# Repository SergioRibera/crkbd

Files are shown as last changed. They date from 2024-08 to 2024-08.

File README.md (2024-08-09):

# Corne keyboard

The Corne keyboard is a split keyboard with 3x6 column staggered keys
and 3 thumb keys, based on [Helix](https://github.com/MakotoKurauchi/helix).
Crkbd stands for Corne Keyboard.

v4

## Latest versions
- corne-cherry: for Cherry MX compatible switches

  - v4 Hotswappable ([JP](docs/corne-cherry/v4/buildguide_jp.md)/[EN](docs/corne-cherry/v4/buildguide_en.md))
  - v4 Soldering (will be released)
- corne-chocolate: for Kailh choc v1 and v2 switches
  - v4 Hotswappable ([JP](docs/corne-chocolate/v4/buildguide_jp.md)/[EN](docs/corne-chocolate/v4/buildguide_en.md)):
  - v4 Soldering (will be released)

- [Corne v4 Cherry Wireless](./pcbs/cherry-wireless)

## Old versions

- corne-classic: for Cherry MX compatible switches 
  - v1 Soldering: ([JP](docs/corne-classic/buildguide_jp.md)/[EN](docs/corne-classic/buildguide_en.md))
- corne-cherry: for Cherry MX compatible switches
  - v2 Hotswappable: ([JP](docs/corne-cherry/v2/buildguide_jp.md)/[EN](docs/corne-cherry/v2/buildguide_en.md))
  - v2 Hotswappable tilting version: ([tilting, JP](docs/corne-cherry/v2/buildguide_tilting_tenting_plate_jp.md)/[tilting, EN](docs/corne-cherry/v2/buildguide_tilting_tenting_plate_en.md)):
  - v3 Hotswappable: ([JP](docs/corne-cherry/v3/buildguide_jp.md)/[EN](docs/corne-cherry/v3/buildguide_en.md))
- corne-chocolate: for Kailh choc v1 switches
  - v2 Hotswappable: ([JP](docs/corne-chocolate/v2/buildguide_jp.md)/[EN](docs/corne-chocolate/v2/buildguide_en.md)):
- corne-light: for easy build with a simple PCB
  - v1 Soldering: ([JP](docs/corne-light/v1/buildguide_jp.md)/[EN](docs/corne-light/v1/buildguide_en.md)):
  - v2 Soldering: ([JP](docs/corne-light/v2/buildguide_low_edition_jp.md)/[EN](docs/corne-light/v2/buildguide_low_edition_en.md)):

## Images

### Cherry
corne-cherry



### Chocolate
corne-chocolate



### Drawing
sketche

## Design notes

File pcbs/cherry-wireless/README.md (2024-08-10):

# Corne Keyboard Wireless Fork

This project is a customized fork of the popular Corne ergonomic keyboard.

> [!NOTE]
> As soon as I have my build I will upload pictures of the finished keyboard.

keyboard pcb

## Disclaimer

> [!IMPORTANT]
> **⚠️ IMPORTANT NOTICE: I am not an electronics expert ⚠️**
>
> This project has been carried out with the help of a professional contracted through Fiverr.
> If you have specific technical questions, I recommend consulting an expert.
>
> https://fiverr.com/pcbdesign_engr

## Features

- Custom layout based on the original Corne
- Hotswap Sockets
- Sk6812MiniE RGB LED per switch
- NRF52840-QIAA-R7 Microcontroller
- Differential pair routing from USB to MCU
- TypeC USB
- NiceView connector
- Removed extra keys added in v4

> [!NOTE]
> According to the engineer in charge, all components available at LCSC JLCPCB were used.

## Project Images

Back 2D
Renderred Back
3DD
3ddd

## Acknowledgements

This project would not have been possible without the help of a talented Fiverr professional. You can find their profile here: https://fiverr.com/pcbdesign_engr

I would also like to thank the original Corne Keyboard community for their incredible work and for inspiring this project.

## License

Use it as you wish, subject to the license of the original project.

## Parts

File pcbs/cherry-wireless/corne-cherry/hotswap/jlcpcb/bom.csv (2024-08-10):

Designator | Footprint | Quantity | Value | LCSC Part #
BT1, BT2, BT3, BT4, rBT1, rBT2, rBT3, rBT4 | Breakaway_Tabs | 8 | Breakaway Tabs
C1, C13, C14, C24, C25, C26, C35, C36, C41, C46, C51, C52 | 0402 | 12 | 4.7uF | C23733
C10, C2, C3, C32, C4, C42, C44, C45 | 0402 | 8 | 100nF | C307331
C11, C33 | 0402 | 2 | 100pF | C1546
C12, C34 | 0402 | 2 | 1nF | C1523
C15, C23, C37, C47, C49, C8 | 0402 | 6 | 1uF | C52923
C16, C38 | 0402 | 2 | 47nF | C312032
C17, C18, C29, C30, C39, C40, C6, C7 | 0402 | 8 | 15pF | C1548
C19, C43 | 0402 | 2 | 100nF | C1525
C20, C50 | 0402 | 2 | 4.7uF
C21, C48 | 0603 | 2 | 10uF | C19702
C22, C27 | 0402 | 2 | 1.5pF | C1552
C28, C31, C5, C9 | 0402 | 4 | 1pF | C1550
D1, rD1 | D_SOD-523 | 2 | 1N4148WT
D2, D4 | 0402 | 2 | BLUE | C364550
D3, D7 | 0402 | 2 | ORANGE | C364554
D5, D6 | D_SOD-323F | 2 | PMEG4010CEJ | C50704
J1, J7 | USB-C_C168688 | 2 | USB_C_Receptacle_USB2.0 | C168688
J11, J3 | PinHeader_1x05_P2.54mm_Vertical | 2 | Screw_Terminal_01x05
J12, J13 | CONN-SMD_SM02B-PASS-TLFSN | 2 | Conn_01x02_Shielded
J2, rJ2 | PJ-398A-5A_PJ-399B-6A | 2 | TRS
J6, J8 | PinHeader_1x03_P2.54mm_Vertical | 2 | Conn_01x03
L1, L5 | 0402 | 2 | 3.9nH | C14033
L2, L6 | 0402 | 2 | 15nH | C27143
L3, L4, L7, L8 | 0603 | 4 | 10uH | C1035
LED1, LED10, LED11, LED12, LED13, LED14, LED15, LED16, LED17, LED18, LED19, LED2, LED20, LED21, LED3, LED4, LED5, LED6, LED7, LED8, LED9, rLED1, rLED10, rLED11, rLED12, rLED13, rLED14, rLED15, rLED16, rLED17, rLED18, rLED19, rLED2, rLED20, rLED21, rLED3, rLED4, rLED5, rLED6, rLED7, rLED8, rLED9 | YS-SK6812MINI-E_crone | 42 | YS-SK6812MINI-E | C5149201
NT1, NT2 | net-tie-2-tiny | 2 | NetTie_2
R1, R13 | 0402 | 2 | 3.9k | C131467
R10, R16, R17, R9 | 0402 | 4 | 5.1k | C105872
R11, R3 | 0402 | 2 | 0R | C17168
R12, R15, R18, R6, R7, R8 | 0402 | 6 | 10k | C25744
R14, R2 | 0402 | 2 | 2M | C138014
R4, R5 | 0402 | 2 | 1.5k | C114759
SW1, rSW1 | keyswitch_cherrymx_hotswap_1.5u | 2 | SW_Push | C2803348
SW10, SW11, SW12, SW13, SW14, SW15, SW16, SW17, SW18, SW19, SW2, SW20, SW21, SW3, SW4, SW5, SW6, SW7, SW8, SW9, rSW10, rSW11, rSW12, rSW13, rSW14, rSW15, rSW16, rSW17, rSW18, rSW19, rSW2, rSW20, rSW21, rSW3, rSW4, rSW5, rSW6, rSW7, rSW8, rSW9 | keyswitch_cherrymx_hotswap_1u | 40 | SW_Push | C2803348
SW22, SW23 | SW-SMD-TS-1088-AR02016 | 2 | SW_SPST
U1, U4 | AQFN-73-1EP_7x7mm_P0.5mm_NRF52840-custom | 2 | NRF52840-QIAA-R7 | C190794
U10, U6 | TDFN-8-1EP_2x2mm_P0.5mm_EP0.8x1.2mm | 2 | MAX17048 | C2682616
U2, U7 | VQFN-16-1EP_3x3mm_P0.5mm_EP1.6x1.6mm | 2 | BQ24075RGT | C2865459
U3, U8 | TSOT-23-5 | 2 | XC6220B331MR | C86534
U5, U9 | UDFN-6_1.2x1.0mm_P0.4mm | 2 | ESDR0502NMUTAG | C94372
Y1, Y3 | Crystal_SMD_2016-4Pin_2.0x1.6mm | 2 | 32MHz | C255896
Y2, Y4 | Crystal_SMD_2012-2Pin_2.0x1.2mm | 2 | 32.768 kHz | C97607
rJP1 | SolderJumper-2_P1.3mm_Open_RoundedPad1.0x1.5mm | 1 | SolderJumper_2_Bridged

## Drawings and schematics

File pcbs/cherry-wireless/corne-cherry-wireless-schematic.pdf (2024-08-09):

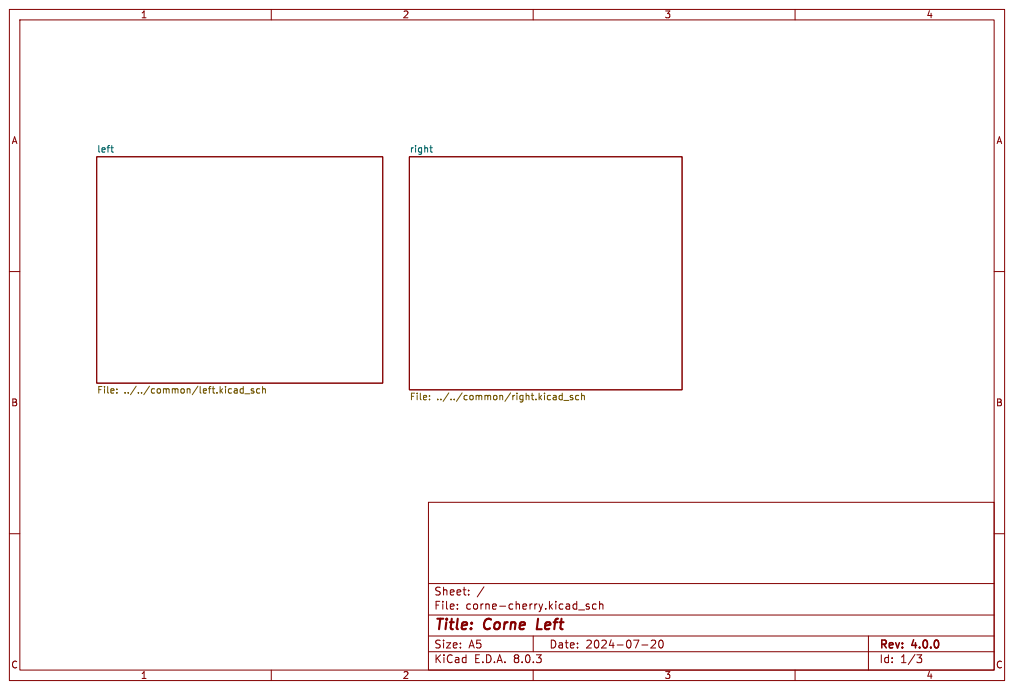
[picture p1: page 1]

left File: ../../common/left.kicad_sch

right File: ../../common/right.kicad_sch

Id: 1/3 Title: Corne Left File: corne-cherry.kicad_sch Sheet: /

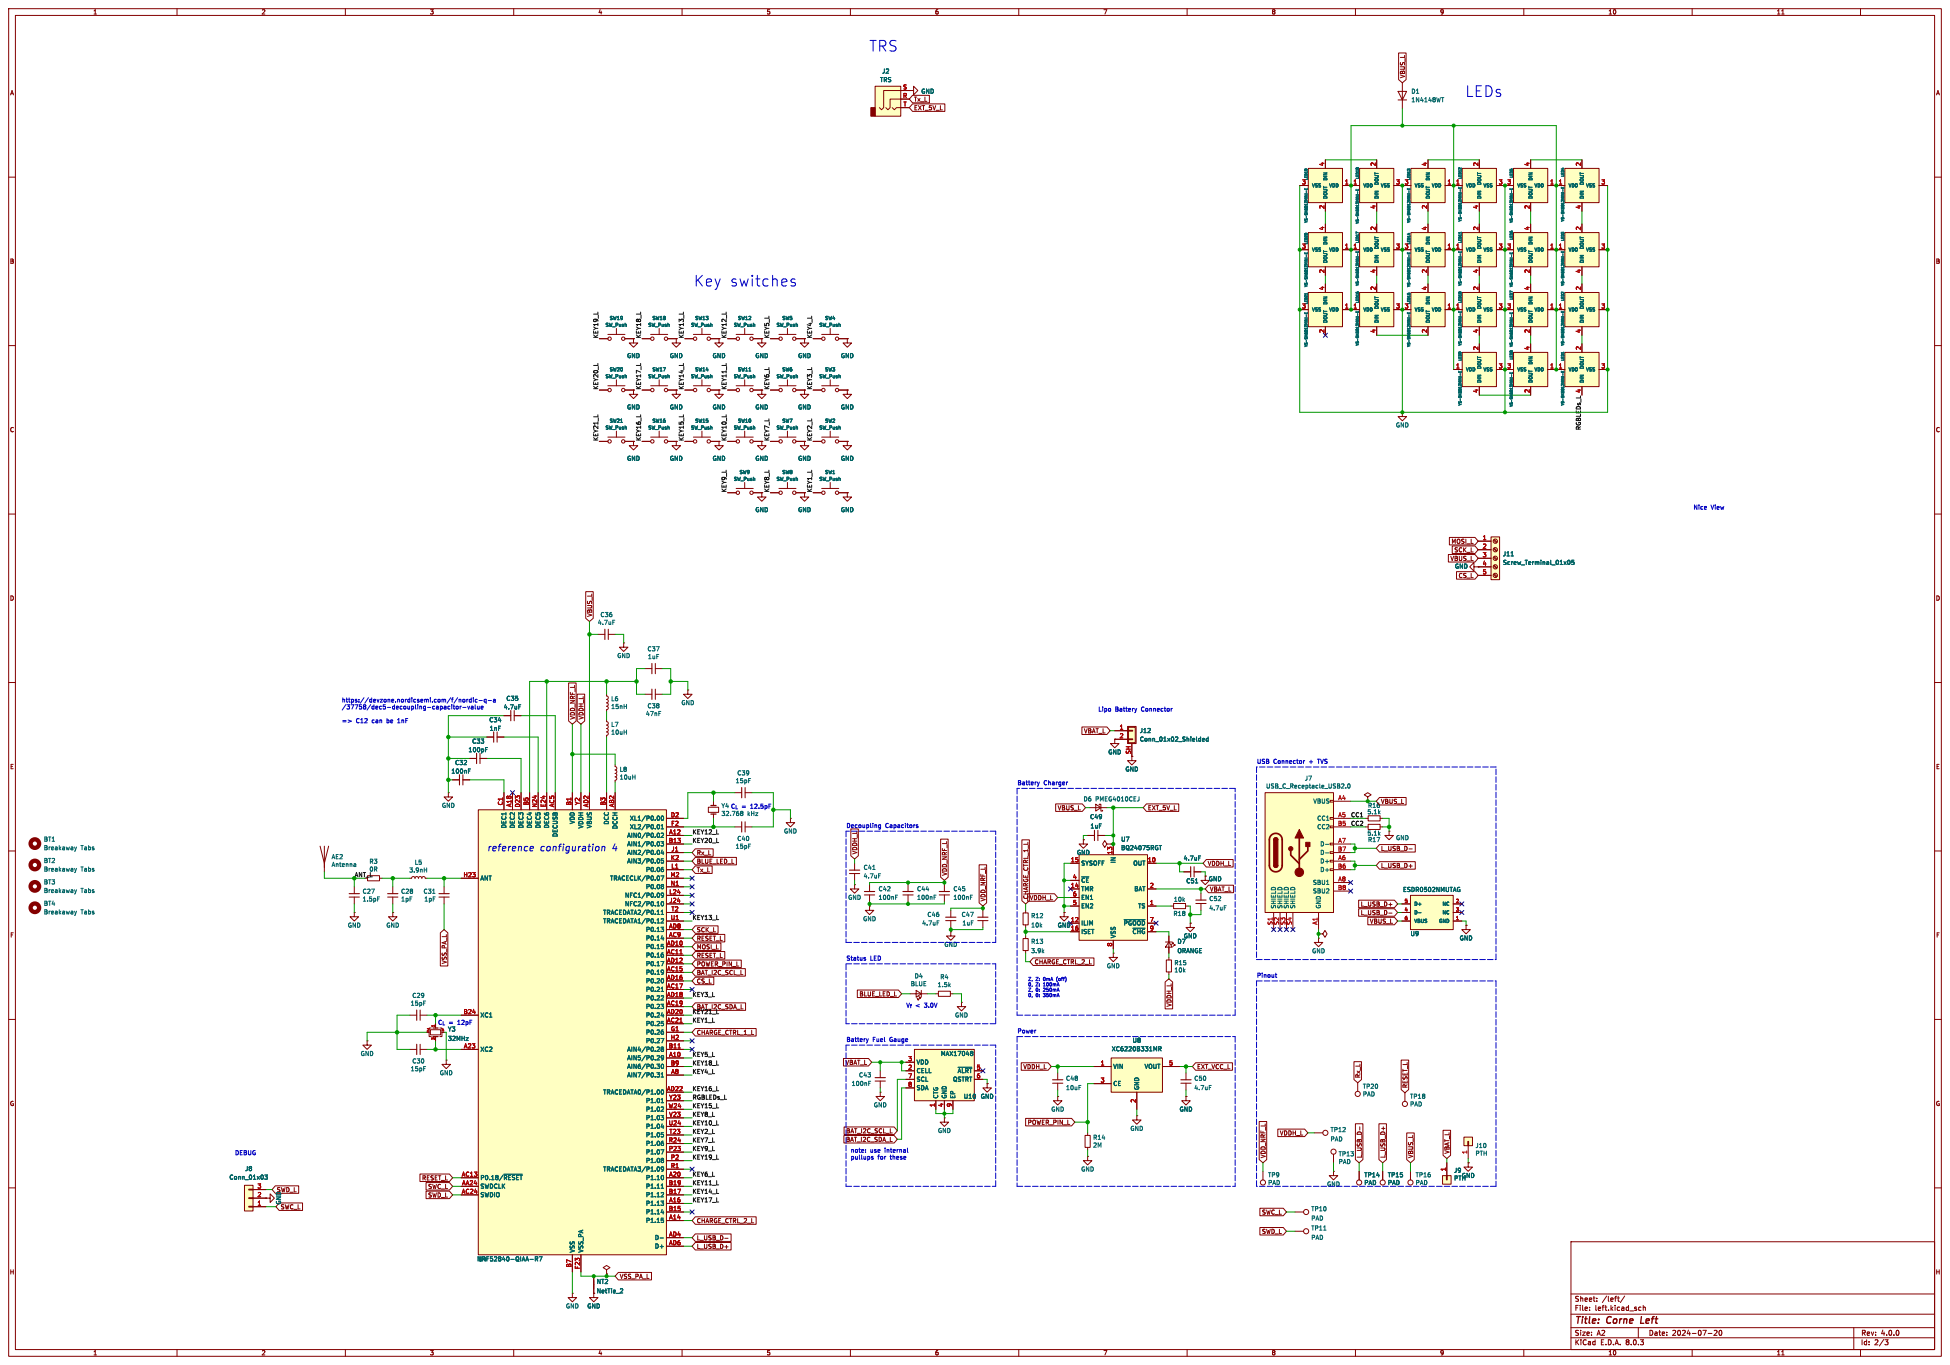
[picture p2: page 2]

VSS 3 DIN 4 LED12 YS-SK6812MINI-E VDD 1 DOUT 2

VSS 3 DIN 4 LED3 YS-SK6812MINI-E VDD 1 DOUT 2

https://devzone.nordicsemi.com/f/nordic-q-a

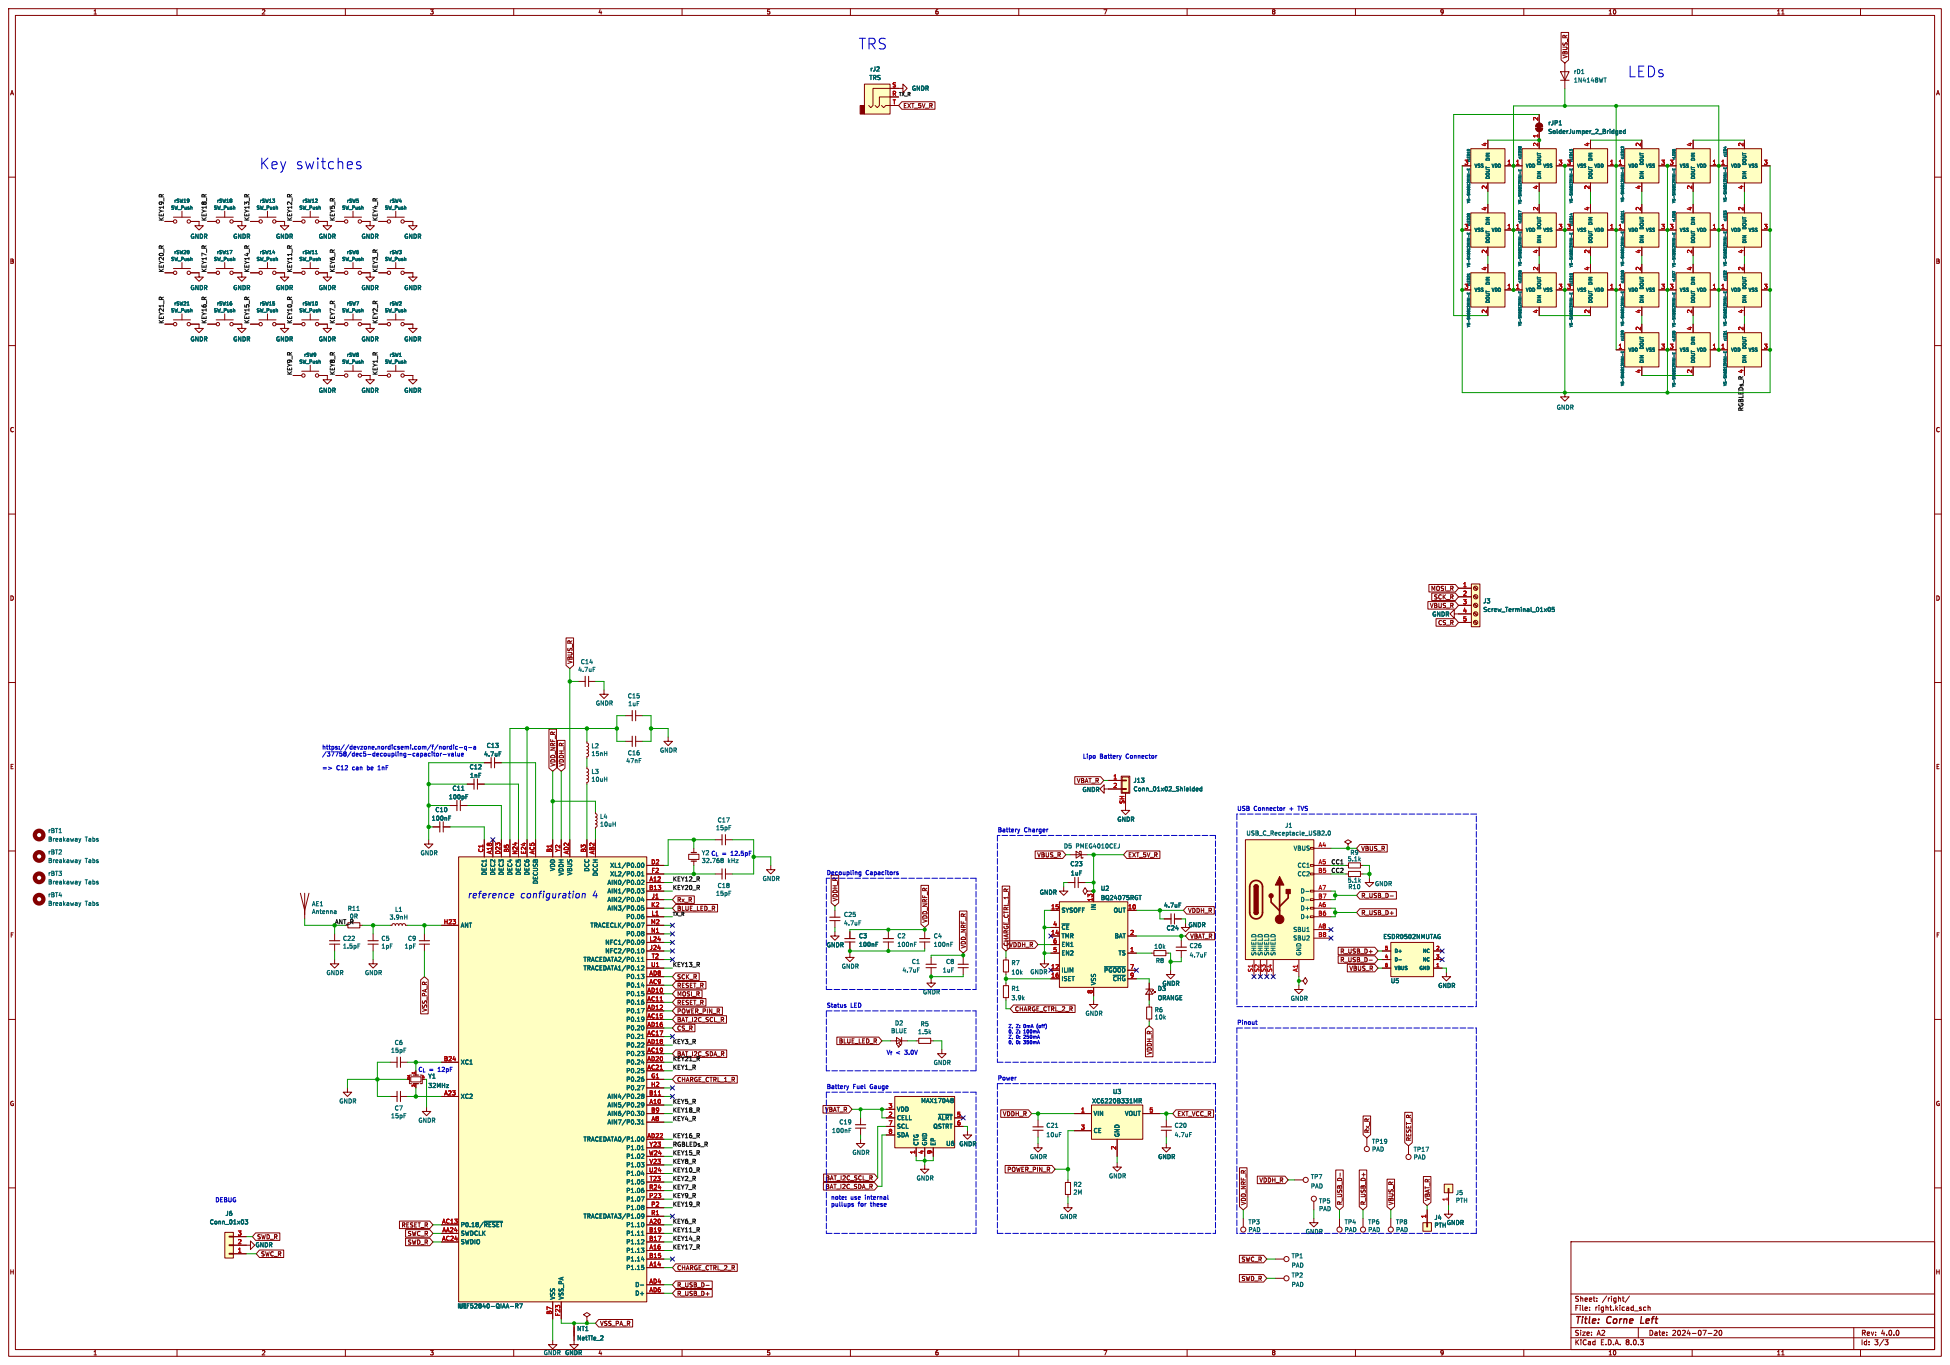
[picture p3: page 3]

https://devzone.nordicsemi.com/f/nordic-q-a

2 CE 3 VOUT 5 GNDR GNDR

4 ~{ALRT}5 QSTRT 6 SCL 7 SDA 8 EP

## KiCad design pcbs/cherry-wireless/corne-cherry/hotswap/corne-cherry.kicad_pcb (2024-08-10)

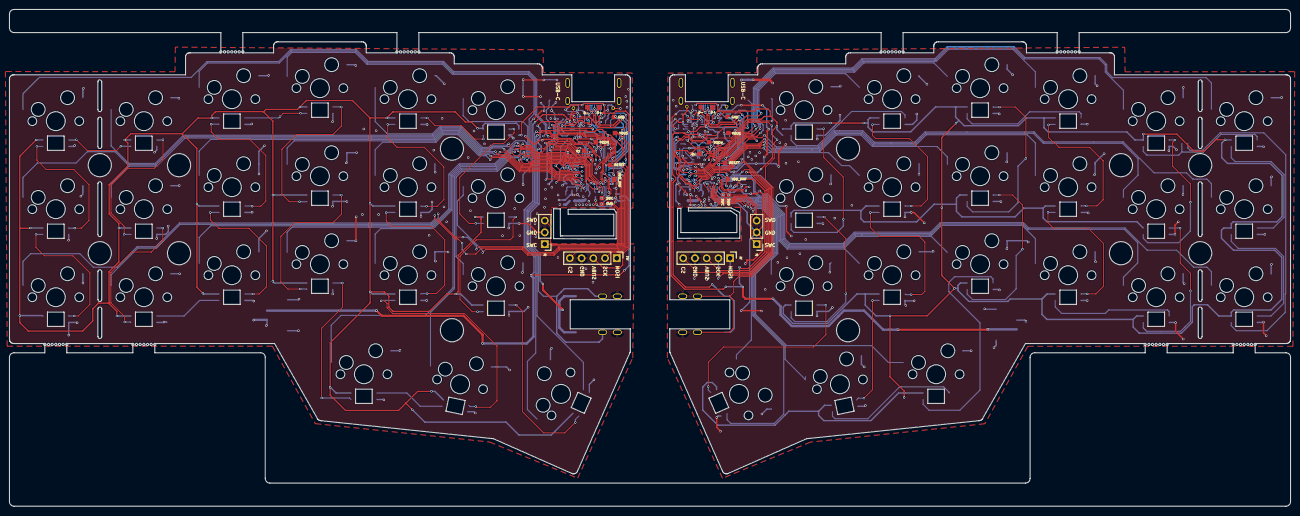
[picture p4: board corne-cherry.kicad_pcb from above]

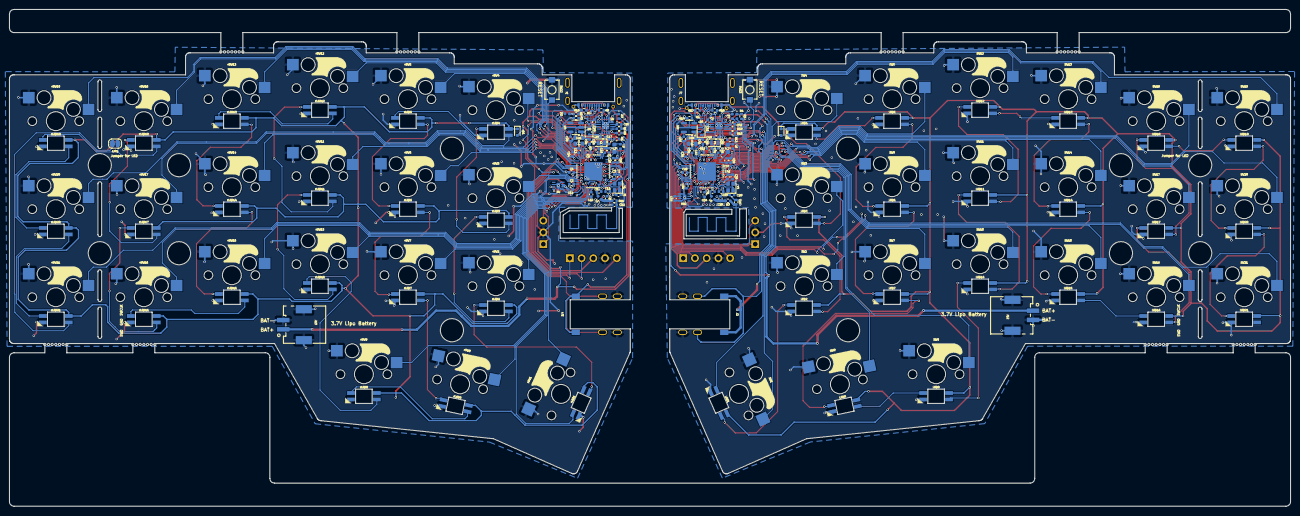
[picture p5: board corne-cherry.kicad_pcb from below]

Board: 2 copper layers, 277.2 x 107.5 mm, 233 parts (201 on the bottom side), 179 nets.

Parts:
AE1, AE2: Antenna; 2.4GHz-meander-antenna-v2
BT1, BT2, BT3, BT4: Breakaway Tabs; Breakaway_Tabs
C1, C13, C14, C20, C24, C25, C26, C35, C36, C41, C46, C50, C51, C52: 4.7uF; C_0402_1005Metric
C2, C3, C4, C10, C19, C32, C42, C43, C44, C45: 100nF; C_0402_1005Metric
C5, C9, C28, C31: 1pF; C_0402_1005Metric
C6, C7, C17, C18, C29, C30, C39, C40: 15pF; C_0402_1005Metric
C8, C15, C23, C37, C47, C49: 1uF; C_0402_1005Metric
C11, C33: 100pF; C_0402_1005Metric
C12, C34: 1nF; C_0402_1005Metric
C16, C38: 47nF; C_0402_1005Metric
C21, C48: 10uF; C_0603_1608Metric
C22, C27: 1.5pF; C_0402_1005Metric
D1: 1N4148WT; D_SOD-523
D2, D4: BLUE; LED_0402_1005Metric
D3, D7: ORANGE; LED_0402_1005Metric
D5, D6: PMEG4010CEJ; D_SOD-323F
J1, J7: USB_C_Receptacle_USB2.0; USB-C_C168688
J2: TRS; PJ-398A-5A_PJ-399B-6A
J3, J11: Screw_Terminal_01x05; PinHeader_1x05_P2.54mm_Vertical
J4, J5, J9, J10: PTH; PTH-0.8_0.45mm
J6, J8: Conn_01x03; PinHeader_1x03_P2.54mm_Vertical
J12, J13: Conn_01x02_Shielded; CONN-SMD_SM02B-PASS-TLFSN
L1, L5: 3.9nH; L_0402_1005Metric
L2, L6: 15nH; L_0402_1005Metric
L3, L4, L7, L8: 10uH; L_0603_1608Metric
LED1, LED2, LED3, LED4, LED5, LED6, LED7, LED8, LED9, LED10, LED11, LED12, LED13, LED14, LED15, LED16, LED17, LED18, LED19, LED20, LED21: YS-SK6812MINI-E; YS-SK6812MINI-E_crone
NT1, NT2: NetTie_2; net-tie-2-tiny
R1, R13: 3.9k; R_0402_1005Metric
R2, R14: 2M; R_0402_1005Metric
R3, R11: 0R; R_0402_1005Metric
R4, R5: 1.5k; R_0402_1005Metric
R6, R7, R8, R12, R15, R18: 10k; R_0402_1005Metric
R9, R10, R16, R17: 5.1k; R_0402_1005Metric
SW1: SW_Push; keyswitch_cherrymx_hotswap_1.5u
SW2, SW3, SW4, SW5, SW6, SW7, SW8, SW9, SW10, SW11, SW12, SW13, SW14, SW15, SW16, SW17, SW18, SW19, SW20, SW21: SW_Push; keyswitch_cherrymx_hotswap_1u
SW22, SW23: SW_SPST; SW-SMD-TS-1088-AR02016
TP1, TP2, TP3, TP4, TP5, TP6, TP7, TP8, TP9, TP10, TP11, TP12, TP13, TP14, TP15, TP16, TP17, TP18, TP19, TP20: PAD; TestPoint_Pad_1.0x1.0mm-nosilk
U1, U4: NRF52840-QIAA-R7; AQFN-73-1EP_7x7mm_P0.5mm_NRF52840-custom
U2, U7: BQ24075RGT; VQFN-16-1EP_3x3mm_P0.5mm_EP1.6x1.6mm
U3, U8: XC6220B331MR; TSOT-23-5
U5, U9: ESDR0502NMUTAG; UDFN-6_1.2x1.0mm_P0.4mm
U6, U10: MAX17048; TDFN-8-1EP_2x2mm_P0.5mm_EP0.8x1.2mm
Y1, Y3: 32MHz; Crystal_SMD_2016-4Pin_2.0x1.6mm
Y2, Y4: 32.768 kHz; Crystal_SMD_2012-2Pin_2.0x1.2mm
rBT1, rBT2, rBT3, rBT4: Breakaway Tabs; Breakaway_Tabs
rD1: 1N4148WT; D_SOD-523
rJ2: TRS; PJ-398A-5A_PJ-399B-6A
rJP1: SolderJumper_2_Bridged; SolderJumper-2_P1.3mm_Open_RoundedPad1.0x1.5mm
rLED1, rLED2, rLED3, rLED4, rLED5, rLED6, rLED7, rLED8, rLED9, rLED10, rLED11, rLED12, rLED13, rLED14, rLED15, rLED16, rLED17, rLED18, rLED19, rLED20, rLED21: YS-SK6812MINI-E; YS-SK6812MINI-E_crone
rSW1: SW_Push; keyswitch_cherrymx_hotswap_1.5u
rSW2, rSW3, rSW4, rSW5, rSW6, rSW7, rSW8, rSW9, rSW10, rSW11, rSW12, rSW13, rSW14, rSW15, rSW16, rSW17, rSW18, rSW19, rSW20, rSW21: SW_Push; keyswitch_cherrymx_hotswap_1u

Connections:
/left/ANT_L: AE2.1 (A), C27.2, R3.2
/left/CC1: J7.A5 (CC1), R16.1
/left/CC2: J7.B5 (CC2), R17.1
/left/KEY1_L: SW1.1, U4.AC21 (P0.25)
/left/KEY2_L: SW2.1, U4.T23 (P1.05)
/left/KEY3_L: SW3.1, U4.AD18 (P0.22)
/left/KEY4_L: SW4.1, U4.A8 (AIN7/P0.31)
/left/KEY5_L: SW5.1, U4.A10 (AIN5/P0.29)
/left/KEY6_L: SW6.1, U4.A20 (P1.10)
/left/KEY7_L: SW7.1, U4.R24 (P1.06)
/left/KEY8_L: SW8.1, U4.V23 (P1.03)
/left/KEY9_L: SW9.1, U4.P23 (P1.07)
/left/KEY10_L: SW10.1, U4.U24 (P1.04)
/left/KEY11_L: SW11.1, U4.B19 (P1.11)
/left/KEY12_L: SW12.1, U4.A12 (AIN0/P0.02)
/left/KEY13_L: SW13.1, U4.U1 (TRACEDATA1/P0.12)
/left/KEY14_L: SW14.1, U4.B17 (P1.12)
/left/KEY15_L: SW15.1, U4.W24 (P1.02)
/left/KEY16_L: SW16.1, U4.AD22 (TRACEDATA0/P1.00)
/left/KEY17_L: SW17.1, U4.A16 (P1.13)
/left/KEY18_L: SW18.1, U4.B9 (AIN6/P0.30)
/left/KEY19_L: SW19.1, U4.P2 (P1.08)
/left/KEY20_L: SW20.1, U4.B13 (AIN1/P0.03)
/left/KEY21_L: SW21.1, U4.AD20 (P0.24)
/left/RGBLEDs_L: LED1.4 (DIN), U4.Y23 (P1.01)
/right/ANT_R: AE1.1 (A), C22.2, R11.2
/right/CC1: J1.A5 (CC1), R9.1
/right/CC2: J1.B5 (CC2), R10.1
/right/KEY1_R: U1.AC21 (P0.25), rSW1.1
/right/KEY2_R: U1.T23 (P1.05), rSW2.1
/right/KEY3_R: U1.AD18 (P0.22), rSW3.1
/right/KEY4_R: U1.A8 (AIN7/P0.31), rSW4.1
/right/KEY5_R: U1.A10 (AIN5/P0.29), rSW5.1
/right/KEY6_R: U1.A20 (P1.10), rSW6.1
/right/KEY7_R: U1.R24 (P1.06), rSW7.1
/right/KEY8_R: U1.V23 (P1.03), rSW8.1
/right/KEY9_R: U1.P23 (P1.07), rSW9.1
/right/KEY10_R: U1.U24 (P1.04), rSW10.1
/right/KEY11_R: U1.B19 (P1.11), rSW11.1
/right/KEY12_R: U1.A12 (AIN0/P0.02), rSW12.1
/right/KEY13_R: U1.U1 (TRACEDATA1/P0.12), rSW13.1
/right/KEY14_R: U1.B17 (P1.12), rSW14.1
/right/KEY15_R: U1.W24 (P1.02), rSW15.1
/right/KEY16_R: U1.AD22 (TRACEDATA0/P1.00), rSW16.1
/right/KEY17_R: U1.A16 (P1.13), rSW17.1
/right/KEY18_R: U1.B9 (AIN6/P0.30), rSW18.1
/right/KEY19_R: U1.P2 (P1.08), rSW19.1
/right/KEY20_R: U1.B13 (AIN1/P0.03), rSW20.1
/right/KEY21_R: U1.AD20 (P0.24), rSW21.1
/right/RGBLEDs_R: U1.Y23 (P1.01), rLED1.4 (DIN)
/right/TX_R: U1.L1 (P0.06), rJ2.R
BAT_I2C_SCL_L: U4.AC15 (P0.19), U10.7 (SCL)
BAT_I2C_SCL_R: U1.AC15 (P0.19), U6.7 (SCL)
BAT_I2C_SDA_L: U4.AC19 (P0.23), U10.8 (SDA)
BAT_I2C_SDA_R: U1.AC19 (P0.23), U6.8 (SDA)
BLUE_LED_L: D4.2 (A), U4.K2 (AIN3/P0.05)
BLUE_LED_R: D2.2 (A), U1.K2 (AIN3/P0.05)
CHARGE_CTRL_1_L: R12.1, U4.G1 (P0.26)
CHARGE_CTRL_1_R: R7.1, U1.G1 (P0.26)
CHARGE_CTRL_2_L: R13.2, U4.A14 (P1.15)
CHARGE_CTRL_2_R: R1.2, U1.A14 (P1.15)
CS_L: J11.5, U4.AD16 (P0.20)
CS_R: J3.5, U1.AD16 (P0.20)
EXT_5V_L: C49.1, D6.1 (K), J2.T, U7.13 (IN)
EXT_5V_R: C23.1, D5.1 (K), U2.13 (IN), rJ2.T
EXT_VCC_L: C50.2, U8.5 (VOUT)
EXT_VCC_R: C20.2, U3.5 (VOUT)
GND: C27.1, C28.1, C29.2, C30.2, C32.2, C33.2, C34.2, C35.2, C36.1, C37.1, C38.1, C39.1, C40.1, C41.1, C42.1, C43.1, C44.1, C45.1, C46.1, C47.1, C48.1, C49.2, C50.1, C51.1, C52.1, J2.S, J7.A1 (GND), J8.2, J10.1, J11.4, J12.2, J12.SH (Shield), LED1.3 (VSS), LED2.3 (VSS), LED3.3 (VSS), LED4.3 (VSS), LED5.3 (VSS), LED6.3 (VSS), LED7.3 (VSS), LED8.3 (VSS), LED9.3 (VSS), LED10.3 (VSS), LED11.3 (VSS), LED12.3 (VSS), LED13.3 (VSS), LED14.3 (VSS), LED15.3 (VSS), LED16.3 (VSS), LED17.3 (VSS), LED18.3 (VSS), LED19.3 (VSS), LED20.3 (VSS), LED21.3 (VSS), NT2.2, R4.1, R14.2, R16.2, R17.2, R18.2, SW1.2, SW2.2, SW3.2, SW4.2, SW5.2, SW6.2, SW7.2, SW8.2, SW9.2, SW10.2, SW11.2, SW12.2, SW13.2, SW14.2, SW15.2, SW16.2, SW17.2, SW18.2, SW19.2, SW20.2, SW21.2, SW23.2 (B), TP13.1, U4.B7 (VSS), U4.EP (VSS), U7.4 (~CE), U7.5 (EN2), U7.8 (VSS), U7.15 (SYSOFF), U7.17 (VSS), U8.2 (GND), U9.1 (GND), U10.1 (CTG), U10.4 (GND), U10.6 (QSTRT), U10.9 (EP), Y3.2, Y3.4
GNDR: C1.1, C2.1, C3.1, C4.1, C5.1, C6.2, C7.2, C8.1, C10.2, C11.2, C12.2, C13.2, C14.1, C15.1, C16.1, C17.1, C18.1, C19.1, C20.1, C21.1, C22.1, C23.2, C24.1, C25.1, C26.1, J1.A1 (GND), J3.4, J5.1, J6.2, J13.2, J13.SH (Shield), NT1.2, R2.2, R5.1, R8.2, R9.2, R10.2, SW22.2 (B), TP5.1, U1.B7 (VSS), U1.EP (VSS), U2.4 (~CE), U2.5 (EN2), U2.8 (VSS), U2.15 (SYSOFF), U2.17 (VSS), U3.2 (GND), U5.1 (GND), U6.1 (CTG), U6.4 (GND), U6.6 (QSTRT), U6.9 (EP), Y1.2, Y1.4, rJ2.S, rLED1.3 (VSS), rLED2.3 (VSS), rLED3.3 (VSS), rLED4.3 (VSS), rLED5.3 (VSS), rLED6.3 (VSS), rLED7.3 (VSS), rLED8.3 (VSS), rLED9.3 (VSS), rLED10.3 (VSS), rLED11.3 (VSS), rLED12.3 (VSS), rLED13.3 (VSS), rLED14.3 (VSS), rLED15.3 (VSS), rLED16.3 (VSS), rLED17.3 (VSS), rLED18.3 (VSS), rLED19.3 (VSS), rLED20.3 (VSS), rLED21.3 (VSS), rSW1.2, rSW2.2, rSW3.2, rSW4.2, rSW5.2, rSW6.2, rSW7.2, rSW8.2, rSW9.2, rSW10.2, rSW11.2, rSW12.2, rSW13.2, rSW14.2, rSW15.2, rSW16.2, rSW17.2, rSW18.2, rSW19.2, rSW20.2, rSW21.2
L_USB_D+: J7.A6 (D+), J7.B6 (D+), TP15.1, U4.AD6 (D+), U9.5 (D+)
L_USB_D-: J7.A7 (D-), J7.B7 (D-), TP14.1, U4.AD4 (D-), U9.4 (D-)
MOSI_L: J11.1, U4.AD10 (P0.15)
MOSI_R: J3.1, U1.AD10 (P0.15)
unnamed: C5.2, L1.1, R11.1
unnamed: C28.2, L5.1, R3.1
unnamed: D1.1 (K), LED1.1 (VDD), LED2.1 (VDD), LED3.1 (VDD), LED4.1 (VDD), LED5.1 (VDD), LED6.1 (VDD), LED7.1 (VDD), LED8.1 (VDD), LED9.1 (VDD), LED10.1 (VDD), LED11.1 (VDD), LED12.1 (VDD), LED13.1 (VDD), LED14.1 (VDD), LED15.1 (VDD), LED16.1 (VDD), LED17.1 (VDD), LED18.1 (VDD), LED19.1 (VDD), LED20.1 (VDD), LED21.1 (VDD)
unnamed: D2.1 (K), R5.2
unnamed: D3.2 (A), R6.2
unnamed: D3.1 (K), U2.9 (~CHG)
unnamed: D4.1 (K), R4.2
unnamed: D7.2 (A), R15.2
unnamed: D7.1 (K), U7.9 (~CHG)
unnamed: L2.2, L3.1
unnamed: L6.2, L7.1
unnamed: LED1.2 (DOUT), LED2.4 (DIN)
unnamed: LED2.2 (DOUT), LED3.4 (DIN)
unnamed: LED3.2 (DOUT), LED4.4 (DIN)
unnamed: LED4.2 (DOUT), LED5.4 (DIN)
unnamed: LED5.2 (DOUT), LED6.4 (DIN)
unnamed: LED6.2 (DOUT), LED7.4 (DIN)
unnamed: LED7.2 (DOUT), LED8.4 (DIN)
unnamed: LED8.2 (DOUT), LED9.4 (DIN)
unnamed: LED9.2 (DOUT), LED10.4 (DIN)
unnamed: LED10.2 (DOUT), LED11.4 (DIN)
unnamed: LED11.2 (DOUT), LED12.4 (DIN)
unnamed: LED12.2 (DOUT), LED13.4 (DIN)
unnamed: LED13.2 (DOUT), LED14.4 (DIN)
unnamed: LED14.2 (DOUT), LED15.4 (DIN)
unnamed: LED15.2 (DOUT), LED16.4 (DIN)
unnamed: LED16.2 (DOUT), LED17.4 (DIN)
unnamed: LED17.2 (DOUT), LED18.4 (DIN)
unnamed: LED18.2 (DOUT), LED19.4 (DIN)
unnamed: LED19.2 (DOUT), LED20.4 (DIN)
unnamed: LED20.2 (DOUT), LED21.4 (DIN)
unnamed: C9.2, L1.2, U1.H23 (ANT)
unnamed: L3.2, U1.B3 (DCC)
unnamed: L4.2, U1.AB2 (DCCH)
unnamed: C10.1, U1.C1 (DEC1)
unnamed: C11.1, U1.D23 (DEC3)
unnamed: C15.2, C16.2, L2.1, U1.B5 (DEC4), U1.E24 (DEC6)
unnamed: C12.1, U1.N24 (DEC5)
unnamed: C13.1, U1.AC5 (DECUSB)
unnamed: C6.1, U1.B24 (XC1), Y1.1
unnamed: C7.1, U1.A23 (XC2), Y1.3
unnamed: C17.2, U1.D2 (XL1/P0.00), Y2.1
unnamed: C18.2, U1.F2 (XL2/P0.01), Y2.2
unnamed: R1.1, R7.2, U2.16 (ISET)
unnamed: R8.1, U2.1 (TS)
unnamed: C31.2, L5.2, U4.H23 (ANT)
unnamed: L7.2, U4.B3 (DCC)
unnamed: L8.2, U4.AB2 (DCCH)
unnamed: C32.1, U4.C1 (DEC1)
unnamed: C33.1, U4.D23 (DEC3)
unnamed: C37.2, C38.2, L6.1, U4.B5 (DEC4), U4.E24 (DEC6)
unnamed: C34.1, U4.N24 (DEC5)
unnamed: C35.1, U4.AC5 (DECUSB)
unnamed: C29.1, U4.B24 (XC1), Y3.1
unnamed: C30.1, U4.A23 (XC2), Y3.3
unnamed: C39.2, U4.D2 (XL1/P0.00), Y4.1
unnamed: C40.2, U4.F2 (XL2/P0.01), Y4.2
unnamed: R12.2, R13.1, U7.16 (ISET)
unnamed: R18.1, U7.1 (TS)
unnamed: rD1.1 (K), rLED1.1 (VDD), rLED2.1 (VDD), rLED3.1 (VDD), rLED4.1 (VDD), rLED5.1 (VDD), rLED6.1 (VDD), rLED7.1 (VDD), rLED8.1 (VDD), rLED9.1 (VDD), rLED10.1 (VDD), rLED11.1 (VDD), rLED12.1 (VDD), rLED13.1 (VDD), rLED14.1 (VDD), rLED15.1 (VDD), rLED16.1 (VDD), rLED17.1 (VDD), rLED18.1 (VDD), rLED19.1 (VDD), rLED20.1 (VDD), rLED21.1 (VDD)
unnamed: rJP1.1 (A), rLED18.2 (DOUT), rLED19.4 (DIN)
unnamed: rJP1.2 (B), rLED21.2 (DOUT)
unnamed: rLED1.2 (DOUT), rLED2.4 (DIN)
unnamed: rLED2.2 (DOUT), rLED3.4 (DIN)
unnamed: rLED3.2 (DOUT), rLED4.4 (DIN)
unnamed: rLED4.2 (DOUT), rLED5.4 (DIN)
unnamed: rLED5.2 (DOUT), rLED6.4 (DIN)
unnamed: rLED6.2 (DOUT), rLED7.4 (DIN)
unnamed: rLED7.2 (DOUT), rLED8.4 (DIN)
unnamed: rLED8.2 (DOUT), rLED9.4 (DIN)
unnamed: rLED9.2 (DOUT), rLED10.4 (DIN)
unnamed: rLED10.2 (DOUT), rLED11.4 (DIN)
unnamed: rLED11.2 (DOUT), rLED12.4 (DIN)
unnamed: rLED12.2 (DOUT), rLED13.4 (DIN)
unnamed: rLED13.2 (DOUT), rLED14.4 (DIN)
unnamed: rLED14.2 (DOUT), rLED15.4 (DIN)
unnamed: rLED15.2 (DOUT), rLED16.4 (DIN)
unnamed: rLED16.2 (DOUT), rLED17.4 (DIN)
unnamed: rLED17.2 (DOUT), rLED18.4 (DIN)
unnamed: rLED19.2 (DOUT), rLED20.4 (DIN)
unnamed: rLED20.2 (DOUT), rLED21.4 (DIN)
POWER_PIN_L: R14.1, U4.AD12 (P0.17), U8.3 (CE)
POWER_PIN_R: R2.1, U1.AD12 (P0.17), U3.3 (CE)
RESET_L: SW23.1 (A), TP18.1, U4.AC9 (P0.14), U4.AC11 (P0.16), U4.AC13 (P0.18/~RESET)
RESET_R: SW22.1 (A), TP17.1, U1.AC9 (P0.14), U1.AC11 (P0.16), U1.AC13 (P0.18/~RESET)
R_USB_D+: J1.A6 (D+), J1.B6 (D+), TP6.1, U1.AD6 (D+), U5.5 (D+)
R_USB_D-: J1.A7 (D-), J1.B7 (D-), TP4.1, U1.AD4 (D-), U5.4 (D-)
Rx_L: TP20.1, U4.J1 (AIN2/P0.04)
Rx_R: TP19.1, U1.J1 (AIN2/P0.04)
SCK_L: J11.2, U4.AD8 (P0.13)
SCK_R: J3.2, U1.AD8 (P0.13)
SWC_L: J8.1, TP10.1, U4.AA24 (SWDCLK)
SWC_R: J6.1, TP1.1, U1.AA24 (SWDCLK)
SWD_L: J8.3, TP11.1, U4.AC24 (SWDIO)
SWD_R: J6.3, TP2.1, U1.AC24 (SWDIO)
Tx_L: J2.R, U4.L1 (P0.06)
VBAT_L: C43.2, C52.2, J9.1, J12.1, U7.2 (BAT), U7.3 (BAT), U10.2 (CELL), U10.3 (VDD)
VBAT_R: C19.2, C26.2, J4.1, J13.1, U2.2 (BAT), U2.3 (BAT), U6.2 (CELL), U6.3 (VDD)
VBUS_L: C36.2, D1.2 (A), D6.2 (A), J7.A4 (VBUS), J11.3, TP16.1, U4.AD2 (VBUS), U9.6 (VBUS)
VBUS_R: C14.2, D5.2 (A), J1.A4 (VBUS), J3.3, TP8.1, U1.AD2 (VBUS), U5.6 (VBUS), rD1.2 (A)
VDDH_L: C41.2, C48.2, C51.2, R15.1, TP12.1, U4.Y2 (VDDH), U7.6 (EN1), U7.10 (OUT), U7.11 (OUT), U8.1 (VIN)
VDDH_R: C21.2, C24.2, C25.2, R6.1, TP7.1, U1.Y2 (VDDH), U2.6 (EN1), U2.10 (OUT), U2.11 (OUT), U3.1 (VIN)
VDD_NRF_L: C42.2, C44.2, C45.2, C46.2, C47.2, L8.1, TP9.1, U4.A22 (VDD), U4.AD14 (VDD), U4.AD23 (VDD), U4.B1 (VDD), U4.W1 (VDD)
VDD_NRF_R: C1.2, C2.2, C3.2, C4.2, C8.2, L4.1, TP3.1, U1.A22 (VDD), U1.AD14 (VDD), U1.AD23 (VDD), U1.B1 (VDD), U1.W1 (VDD)
VSS_PA_L: C31.1, NT2.1, U4.F23 (VSS_PA)
VSS_PA_R: C9.1, NT1.1, U1.F23 (VSS_PA)

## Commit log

2024-08-09 add corne cherry wireless
    [BOM-corne-cherry.csv, corne-cherry.kicad_pcb, corne-cherry.kicad_sch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]
2024-08-10 update wireless version readme.md
2024-08-10 update corne cherry wireless
    [BOM-corne-cherry.csv, bom.csv, corne-cherry.kicad_pcb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]
